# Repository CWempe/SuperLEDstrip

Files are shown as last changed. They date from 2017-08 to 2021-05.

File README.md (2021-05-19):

# SuperLEDstrip

I started this project as a gift for my little cousin.
The goal was to create an LED strip that could be controlled by a kid via touchscreen.
The graphical layout is based on [Googles Material Design Guidelines](https://material.io/guidelines/material-design/introduction.html).

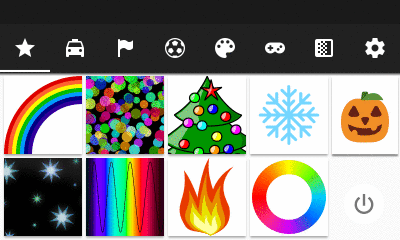
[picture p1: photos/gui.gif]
display animation


SuperLEDstrip v1.0 (http://www.youtube.com/watch?v=CBAr6hmqsu4)

## Requirements

### Hardware

* [**Wemos D1 mini**](https://www.wemos.cc/)  
  An ESP8266 device is nice, because it is litte, cheap and we can add Wifi features later.  
  But any other Arduino compatible device should do.
* [**WS2812B LED strip**](https://de.aliexpress.com/item/2036819167.html)  
  or any other LED strip that is [suported by FastLED](https://github.com/FastLED/FastLED#supported-led-chipsets)
  * It is recommended to use a **capacitor** to smooth out the power supply.  
      I used one with *1000 µF* and *16 V*.
  * [**SK6812**](https://de.aliexpress.com/item/32476317187.html) is also supported since v2.7.0.  
    Define `FASTLED_RGBW` in `custom_values.h`.
    * the white channel is irgnored for now
* **level shifter** from 3.3V to 5V  
  like [Texas Instruments SN74HCT245N](http://www.ti.com/lit/ds/symlink/sn74hct245.pdf)
  * a 20 pin **IC socket** for this chip is a good idea, too
* [**DHT22**](https://www.aliexpress.com/wholesale?SearchText=dht22&opensearch=true)
  to get current temperture and humidity  
  This is not necessary, but it is very cheap. So why not?
* [**Nextion HMI touch screen**](https://nextion.itead.cc/)  
  I used the 3.2" basic model ([NX4024T032](https://www.itead.cc/wiki/NX4024T032))
  You cannot simply use another size without putting much effort into resizing all graphics!
  * a few **connectors** to make it easier to (dis-)connect the display  
    [XHP-4](http://www.jst-mfg.com/product/pdf/eng/eXH.pdf)  
  * a **microSD** card to flash the firmware to the display
* **Power supply** like [this](https://de.aliexpress.com/item/5V-LED-Power-Supply-1A-2A-3A-6A-8A-10A-Switching-Adapter-AC110-240V-AC-to/32810906485.html)
  * a suitable male adapter like [these](https://de.aliexpress.com/item/10-pair-Led-Light-Strip-connector-DC-male-to-DC-female-Plug-Jack-cctv-connect-Adapter/1672619063.html) (not tested)
* **470Ω resistor**
* some more tools, cables and connectors
  * I used [Phoenix Contact MC 1,5/ 3-ST-3,5](http://www.produktinfo.conrad.com/datenblaetter/725000-749999/740631-da-01-en-LEITERPLATTENSTECKER_MC_1_5__3_ST_3_5.pdf) and [MCV 1,5/ 3-G-3,5](http://www.produktinfo.conrad.com/datenblaetter/725000-749999/740686-da-01-en-LEITERPLATTENSTECKER_MCV_1_5__3_G_3_5.pdf) to connect the LED cables, because they are small and are specified to work with the expected current..  
   But they are not good looking.
  * adding a **fuse** is a good idea for security, too

### Software

Using VisualStudio Code and the PlatformIO Extension the necessary libraries are installed automatically vis `platformio.ini`.

Here is the Dependency Graph with the latest successfully tested versions.

```
Dependency Graph
|-- <Homie> 3.0.1
|   |-- <ArduinoJson> 6.11.5
|   |-- <AsyncMqttClient> 0.8.2
|   |   |-- <ESPAsyncTCP> 1.2.0
|   |   |   |-- <ESP8266WiFi> 1.0
|   |-- <Bounce2> 2.55.0
|   |-- <ESP Async WebServer> 1.2.3
|   |   |-- <ESPAsyncTCP> 1.2.0
|   |   |   |-- <ESP8266WiFi> 1.0
|   |   |-- <Hash> 1.0
|   |   |-- <ESP8266WiFi> 1.0
|   |   |-- <ArduinoJson> 6.11.5
|   |-- <Ticker> 1.0
|   |-- <ESP8266WiFi> 1.0
|   |-- <DNSServer> 1.1.1
|   |   |-- <ESP8266WiFi> 1.0
|   |-- <ESP8266HTTPClient> 1.2
|   |   |-- <ESP8266WiFi> 1.0
|   |-- <ESPAsyncTCP> 1.2.0
|   |   |-- <ESP8266WiFi> 1.0
|   |-- <ESP8266mDNS> 1.2
|   |   |-- <ESP8266WiFi> 1.0
|-- <ArduinoJson> 6.11.5
|-- <ESPAsyncTCP> 1.2.0
|   |-- <ESP8266WiFi> 1.0
|-- <DHT sensor library> 1.4.0
|   |-- <Adafruit Unified Sensor> 1.1.4
|-- <DallasTemperature> 3.9.1
|   |-- <OneWire> 2.3.5
|-- <OneWire> 2.3.5
|-- <Nextion> 0.0.0+20201108223110.sha.b8e2a3b
|   |-- <EspSoftwareSerial> 6.8.5
|-- <Embedis> 1.2.0
|-- <Adafruit Unified Sensor> 1.1.4
|-- <elapsedMillis> 1.0.6
|-- <FastLED> 3.3.3
|   |-- <SPI> 1.0
|   |-- <EspSoftwareSerial> 6.8.5
|-- <EEPROM> 1.0
|-- <EspSoftwareSerial> 6.8.5
```

In case you want to edit the content of the display to use other theme colors or add/replace some LED patterns, you also need the following programs.  
Only tested and used with Windows 10.

* [**Nextion Editor**](https://nextion.itead.cc/resource/download/nextion-editor/)  
   This software is needed if you want to change the content of the display
* [**Inkscape**](https://inkscape.org/download)  
   to edit the graphics
* [**inkmake**](https://github.com/wader/inkmake)  
   to automatically create and export the necessary png files from the svg file
  * requires [Ruby](http://rubyinstaller.org/)
* [**msxml**](https://www.microsoft.com/en-us/download/details.aspx?id=21714)  
   to automatically replace colors in the svg file before exporting to png

### Preparation

#### Nextion

Before you can start to compile the project you need to make some changes to the Nextion library.

This is already done in the branch linked in the `platformio.ini`.

Open the following file with a text editor.  
`C:\Users\<username>\Documents\Arduino\libraries\ITEADLIB_Arduino_Nextion\NexConfig.h`

Disable debug by commenting it.

```c
//#define DEBUG_SERIAL_ENABLE  
```

And replace

```c
//#define nexSerial Serial
```

with

```c
#include <SoftwareSerial.h>
extern SoftwareSerial HMISerial;
#define nexSerial HMISerial
```

see:

* <https://github.com/itead/ITEADLIB_Arduino_Nextion#uno-like-mainboards>
* <https://www.reddit.com/r/arduino/comments/4b6jfi/nexconfigh_for_nextion_display_on_arduino_uno/>

You also might want to change some custom values in `custom_values.h`.  
Like `DISPLAY_TITLE`, `DATA_PIN`, `NUM_LEDS`, `LEDS_PER_METER`, `LED_TYPE` or `COLOR_ORDER`.

When using the custom FastLED library you are also able to use RGBW SK6812 strips and DMA mode by defining these features.

## Usage

First you need to combine the hardware components.

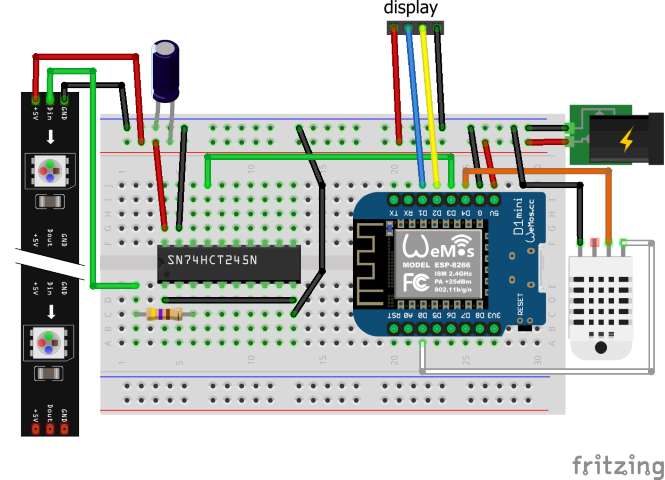
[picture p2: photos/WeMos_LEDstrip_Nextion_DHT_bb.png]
breadboard view


There is also a [pcb view][pcb] when you are done testing. (not tested!)

Next you need to compile and upload the Arduino sketch to your device.
After you installed the libraries you define the parameters of your device before you can hit the upload button.

Be aware to **not connect the LED stripe while the system is only powered by usb** via the Arduino, because this will put to much power through the Arduino. I recomment to disconnect the LED strip and the display while programming the Arduino.

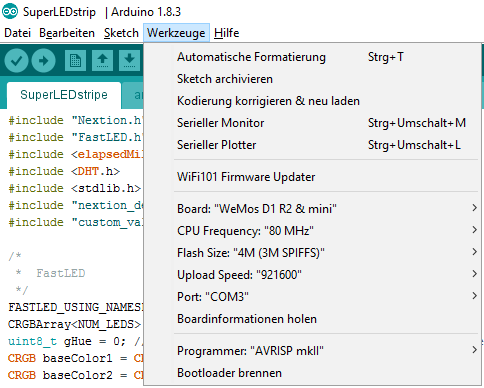
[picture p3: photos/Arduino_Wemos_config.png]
configure serial parameters for Wemos in Arduino


After this you copy the compiled HMI file (will be uploaded to the release page) to an FAT32 formatted microSD card, plug it into the display, and connect power to the display. This will automatically start the flashing of the firmware.

## Customizing

### WLED

Since version `3.1.0` SuperLEDstrip supports controlling a [WLED](https://github.com/Aircoookie/WLED) device.

* Configure `WLED_JSON_URL` in `custom_values.h` befor compiling
* Tested with wled version `0.12.0`.
* Not all scenes look identical to SuperLEDstrip.
* Arcade scenes are not supported.

### Buttons

You can configure the purpose of your buttons in `custom_values.h`.
Like changing tha state of one or multiple output pins or switching between pre-defined scenes.
Just change the values of `button01_do[]`.

### Outputs

You can also define some output pins in `custom_values.h`.
They can be inverted and you can define the initial state at start up.

### Arduino Code

Let's say you want to add an LED pattern you developed as the function `mynewpattern()`.

First you need to add the pattern in `SuperLEDstripe.ino` if you create a new animation.
If your are only ading a new color pattern for an existing animation (like `runningPalette`) you can skip this part.

```c
//     Pattern IDs              0          1      2         3        4    5     6               7              8     9        10  
SimplePatternList gPatterns = { oneColor, stars, confetti, rainbow, bpm, kitt, flashingLights, runningPalette, xmas, Fire2012,  mynewpattern};
```

Add the new secen to the `setScene()` function in `led_functions.h`.

```c
    case 304:   // swedish flag
      setupPaletteSweden();
      break;
```

While you are developing you might want to change the default scene to be your new one.

```c
#define DEFAULT_SCENE      304
```

To start the pattern from a cell (virtual button) from the display, you add the pattern to the according callback function in `nextion_callback_functions.h`.  
Here it is `p01c07PopCallback` (p01 = page 1; c07 = cell 7).

```c
void p01c07PopCallback(void *ptr) { gCurrentPatternNumber = 10; }
```

### Display Graphics

You also need to change the graphics of the display, if you add a new pattern.
First you need to download some pictures from the internet that are not includes in this project.

```c
./Display/exported/get_images.sh
```

Now you can open the `Display\exported\display_matarial_design.svg` with Inkscape and enable the **object manger**.
Next you insert or create your new graphic (we will call it "tile" on top of the cell and group this with the object manager under the tile group of your choice (e.g. "tiles specials").
This is necessary, because the export script will automatically mark the different tile groups as (in-)visible.

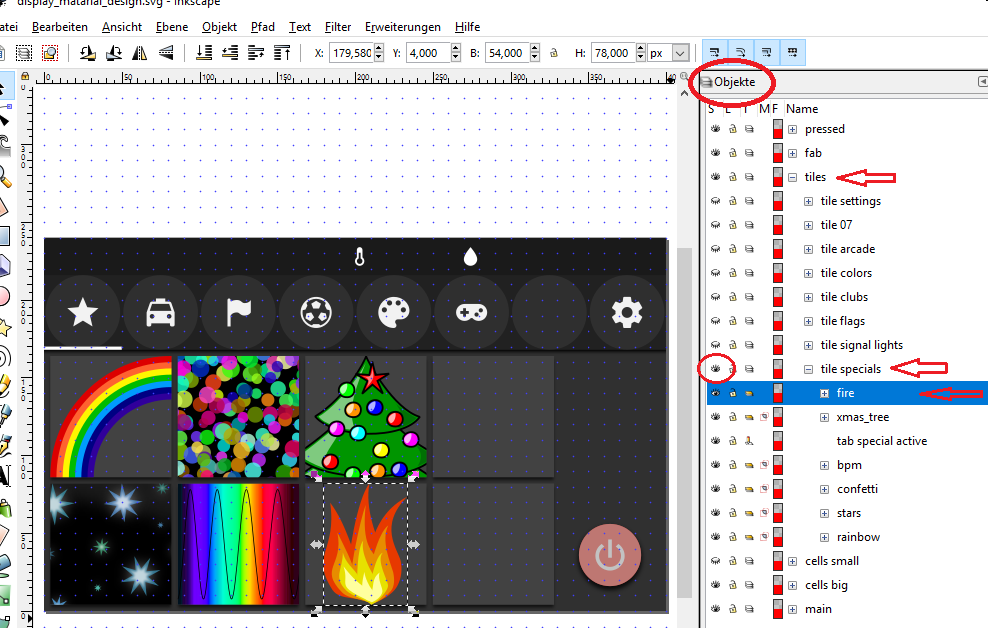
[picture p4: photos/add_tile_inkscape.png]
add tile to graphics


In case you manually export the graphics you might want to change the theme colors and make the individual groups (in-)visible before each export.
For each tile group (settings, flags, ...) you need two exports. One with the `pressed` group disabled and one with it enabled.

The export script `Display\exported\create_colored_svg_custom.bat` will do all this automatically.
To use other theme colors you can change these in line 20.

```c
call:SetColor  dark, white
```

If you run `create_colored_svg.bat` the script will create **all possible color combinations** according to [Googles material design color palette](https://material.io/guidelines/style/color.html#color-color-tool).
It took my computer about **24 hours** to do this!

After the graphics are exported you need to replace the old ones in the Nextion file.  
Open `Display\400x240_black_white_light.HMI` with the Nextion Editor.

Each tabulator of the interface has two pictures within the Nextion file. One with and one without 'pressed' objects.
So for the first tab you need to replace pictures 1 and 2.
Then you select the page (top right corner) and the tile you want the new pattern to be displayed at (here: `p01c07`) and change the attributes (bottem right) `picc` to `1` and `picc2` to `2`.

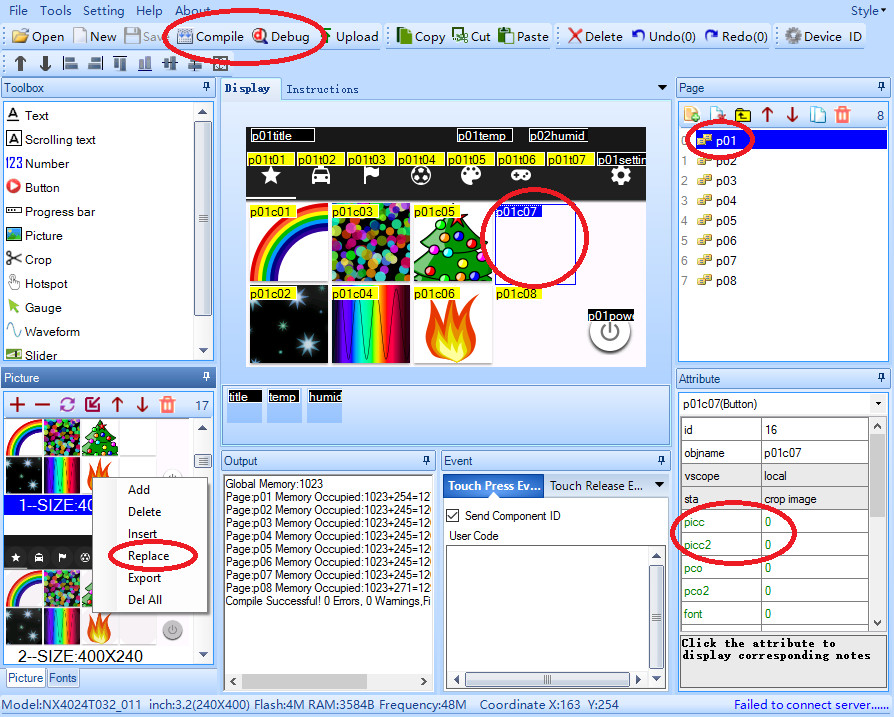
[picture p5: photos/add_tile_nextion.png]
add tile to display


Now you can see the result by clicking `Debug` or hit `Compile` to create a binary file. Put this file (*File | Open build folder*) in the root directory of your microSD card , put it into the display, connect power and wait while the new firmware is flashed.

## OTA-Update

With the integration of homie-esp8266 there comes the ability to flash the firmware via wifi.

* make sure the device is connected to your mqtt broker
* install and configure the [homie-ota server](https://github.com/jpmens/homie-ota)
* download the latest binary firmware release or compile it yourself with the Arduino IDE and select *Sketch | Export compiled Binary*
* Upload the firmware via the web interface of homie-ota or with the `upload_firmware.sh` script
* select firmware and device in the web interface and start the process

## Upload config.json (SPIFFS)

Instead of configuriong your device via the Config-Mode of Homie, you can define your Homie-Configuration in `Data/config.json'.
To upload the file via Seriel (USB) connection use the following command:

`pio run -t uploadfs`

If you use a `d1_mini_pro` board you still need to define `board = d1_mini` in your `platformio.ini`.
Otherwise you get an `std::bad_alloc` error.

## openHAB

Once you got your device connected to your mqtt broker you can configure your smart home (in this case [openHAB](http://www.openhab.org/)) to control SuperLEDstrip.

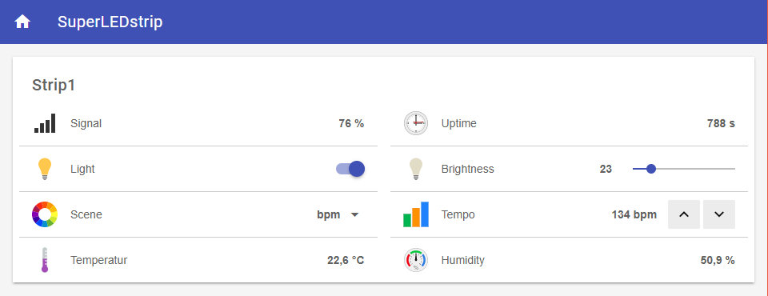
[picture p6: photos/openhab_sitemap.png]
openhab_sitemap


You can find configuration examples in the `openhab` folder.

[display_gif]: photos/gui.gif
[breadboard]: photos/WeMos_LEDstrip_Nextion_DHT_bb.png
[pcb]: photos/WeMos_LEDstrip_Nextion_DHT_pcb.png
[Arduino_Wemos_config]: photos/Arduino_Wemos_config.png
[add_tile_inkscape]: photos/add_tile_inkscape.png
[add_tile_nextion]: photos/add_tile_nextion.png
[openhab_sitemap]: photos/openhab_sitemap.png

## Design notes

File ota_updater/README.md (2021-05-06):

# OTA Update for Homie via MQTT

Example:

```powershell
cd ./ota_updater
pip install -r requirements.txt

python ota_updater.py -l hostname -u user -d password -t "homie/" -i "devicename" ..\.pio\build\d1_mini_pro\firmware.bin

Source: https://github.com/homieiot/homie-esp8266/tree/develop/scripts/ota_updater

Documentation: https://homieiot.github.io/homie-esp8266/docs/3.0.1/others/ota-configuration-updates/
```

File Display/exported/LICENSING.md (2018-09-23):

# halloween pumpkin
source: https://commons.wikimedia.org/wiki/File:Twemoji_1f383.svg

Licens: Creative Commons Attribution 4.0 International license.

https://creativecommons.org/licenses/by/4.0/legalcode

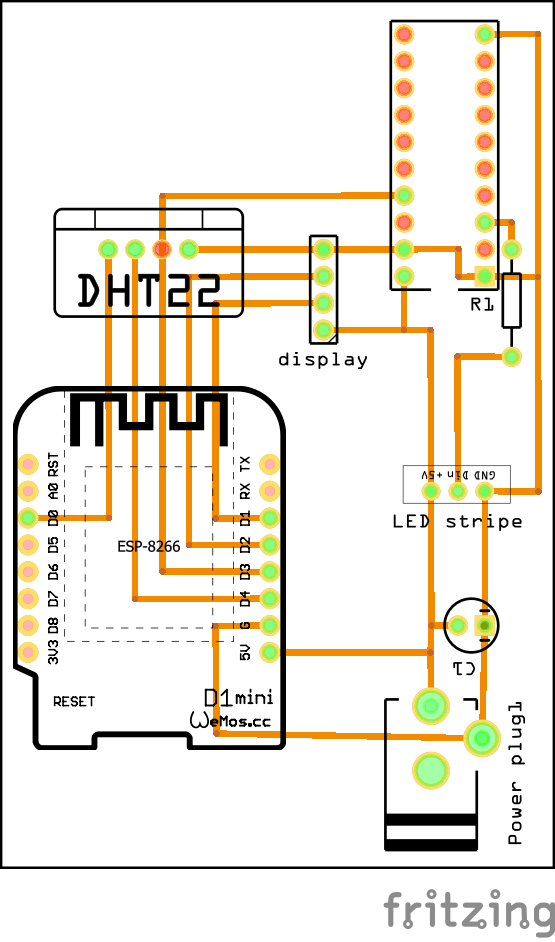
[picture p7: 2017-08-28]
photos/WeMos_LEDstrip_Nextion_DHT_pcb.png

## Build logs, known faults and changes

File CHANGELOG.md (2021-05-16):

# Changelog

## 3.1.0

* Controll a [WLED](https://github.com/Aircoookie/WLED) device (see README)

## 3.0.0

* Switching to Homie 3.0.1 with support of Homie convention v3.0.1
* Control WLED Relay via brightness
* Add `RELAIS_ALWAYS_ON` for WLED pcb

## 2.7.0

* limited support for RGBW (SK6812 LEDs)
* using official FastLED library again

## 2.6.1

* Add pattern "lightsaber"

## 2.6.0

* Make BUTTON01 configurable via `custom_values.h`
* Add OUTPUT pins and make them configurable via `custom_values.h`

## 2.5.4

* Add version number to display

## 2.5.3

* Add USA flag

## 2.5.2

* Make pre defined palletes and pallete scenes selectable via Display

## 2.5.1

* Add support for Button01
  Changes between pre defined scenes

## 2.5.0

* Add color palletes
  * Add pre defines color palletes
  * Add pallete scenes (animation styles) `static pallete`, `running pallete` and `color rotation`
  * Make palletes and pallete scenes selectable via mqtt
  * Make pallete size changeable (via mqtt)
  * Save pallete to eeeprom and restore after reboot

## 2.4.1

* Add option to use DS18B20 instead of DHT22 sensor or neither

## 2.4.0

* Add pattern "custom color"
  * Add support to save and load tweo different custom colrs

## 2.3.0

* Migrate to PlatformIO
* Add option to correct color and color temperature via FastLED
* Move random color pattern to arcade tab
* Add support for RGBW and DMA via custom library ([coryking/FastLED](https://github.com/coryking/FastLED))
* Add support for external graphics in display svg
* Add patterns
  * spanish flag
  * halloween

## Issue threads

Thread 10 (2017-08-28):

add more flags

CWempe, 2017-08-28:
Like

☑ Sweden
☐ England
☐ France
☐ Denmark
☐ Belgium

CWempe, 2017-11-21:
done in new brnach
https://github.com/CWempe/SuperLEDstrip/tree/homie_new_pattern_2017

see: 2b802331c598507a2e48139dd99892c08f5f4497

CWempe, 2017-11-22:
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

Closed 2017-11-21.

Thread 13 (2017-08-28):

add Hue emulation

CWempe, 2017-08-28:
possible projects for inpiration:

* https://github.com/mariusmotea/diyHue
* https://github.com/probonopd/ESP8266HueEmulator

This might add Amazon Alexa support. 😉

needs #3

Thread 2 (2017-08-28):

save last state in persistent memory

CWempe, 2017-08-28:
It would be great if the last choosen led pattern would be saved in EEPROM and be activated after truning the device back on.

This link might help: https://github.com/esp8266/Arduino/tree/master/libraries/EEPROM

CWempe, 2018-09-21:
Fixed in 2712463d415de431c2159e20ac3b4247b710cf4c

Closed 2018-09-21.

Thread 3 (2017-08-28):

add wifi support

CWempe, 2017-08-28:
If this project would support wifi it would be possible to add many nice features that will be mentioned in additional issues.

I guess this would be the best way to integrate wifi.
https://github.com/tzapu/WiFiManager

Additionally it would be nice to show the wifi status on the display and maybe add a wps button in the settings page.

CWempe, 2017-09-01:
I started to integrate homie-esp8266.
see https://github.com/CWempe/SuperLEDstrip/tree/homie

So it supports the following features:

* wifi #3
* mqtt #7
  only device basics, nothing related to LEDs
* OTA-update #5

There may be unknown limitations or disadvantages with this release.
After the first

CWempe, 2017-11-22:
implemented in 78a719ce6630ef17b05810464e2b892e0cef193f

Closed 2017-11-22.

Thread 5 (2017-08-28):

add support for OTA update

CWempe, 2017-08-28:
possibly by adding the [homie framework](https://github.com/marvinroger/homie-esp8266).

Or based on [Sonoff-Tasmota](https://github.com/arendst/Sonoff-Tasmota/)

needs or replaces #3

CWempe, 2017-09-02:
OTA works with the `homie` branch

CWempe, 2017-11-22:
implemented in 60f0dc872d6690895a712106d1c0d880bed533d0

Closed 2017-11-22.

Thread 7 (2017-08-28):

add mqtt support

CWempe, 2017-08-28:
To connect SuperLEDstripe with any kind of smart home it would be great if this project would support [mqtt](http://mqtt.org/).

This requires #3 and might be possible via Homie or Sonoff-Tasmota like mentioned in #5

CWempe, 2017-09-02:
OTA works with the `homie` branch

CWempe, 2017-09-03:
This might be interessting to controll the light via mqtt with openhab.

https://community.openhab.org/t/rgb-led-strip-control-using-arduino-and-mqtt/4366

CWempe, 2017-11-22:
implemented in https://github.com/CWempe/SuperLEDstrip/commit/0126e3e5c56878e3f00e627a10286a83b153a4bb

Closed 2017-11-22.

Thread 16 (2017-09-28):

estimate power consumption

CWempe, 2017-09-28:
Using the following function it shoulkd be possible to estimate the power consumption of the LED strip.
Maybe adding some mW for Arduino and Display.

http://fastled.io/docs/3.1/group___power.html#ga594568be6aba941c635193a6d46f715e

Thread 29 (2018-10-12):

Add support for defining rgb values separately

CWempe, 2018-10-12:
There should be an option to define `rgb` values separately.

# Examples

## mqtt

```
homie/SuperLEDstrip/led/color/set 179,121,63
```

## Display

*mockup*

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

Better use sliders.
https://material.io/design/components/sliders.html#discrete-slider

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

# preperations

* move `colorwheel` tile top `arcade` tab to make room on the `color` tab
*

# features

- [ ] store values in spiff
  * save and load three custom solors
  * not save every change. Let user choose to save current state.
- [ ] restore values and `FastLED.show()` when tile gets opened
- [ ] prepare for future `rgbw` support

CWempe, 2018-11-30:
added in v2.4.0 (e8eb2fa895fcd16d45fbc64f6bade74e0214a76d)

Closed 2018-11-30.

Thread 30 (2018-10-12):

Fix warnings found by PlatformIO

CWempe, 2018-10-12:
When comiling with PlatformIO there are several warnings like the following.

```
C:\Users\cwempe\.platformio\packages\framework-arduinoespressif8266\libraries\SoftwareSerial\SoftwareSerial.cpp: In member function 'void SoftwareSerial::rxRead()':
C:\Users\cwempe\.platformio\packages\framework-arduinoespressif8266\libraries\SoftwareSerial\SoftwareSerial.cpp:219:16: warning: comparison between signed and unsigned integer expressions [-Wsign-compare]
if (next != m_outPos) {
^

.piolibdeps\Nextion_ID37\NexPage.cpp: In member function 'bool NexPage::show()':
.piolibdeps\Nextion_ID37\NexPage.cpp:25:13: warning: unused variable 'buffer' [-Wunused-variable]
uint8_t buffer[4] = {0};
^
```

CWempe, 2018-11-30:
Fixed almost all in a2f44fe2a5357fa0bc315a70bcc254fc4be914c6

Closed 2018-11-30.

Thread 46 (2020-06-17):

Set versionss of libraries in platformio.ini

CWempe, 2020-06-17:
Some newer libraries create problems.
`platformio.ini` should have the working versions predefined.

CWempe, 2020-06-17:
This might help:

```ini

     ; Homie@2.0.0
     Homie
     ; ESPAsyncTCP@1.2.0
     ESPAsyncTCP
     ; DHT sensor library@1.3.4
     DHT sensor library
     DallasTemperature
     ; OneWire@2.3.4
     OneWire
     Nextion
     ; FastLED_RGBW=git@github.com:coryking/FastLED.git
     FastLED_RGBW=git@github.com:cwempe/FastLED.git#support_new_esp8266_lib
     Embedis
     Adafruit Unified Sensor
     ; elapsedMillis@1.0.4
     elapsedMillis
```

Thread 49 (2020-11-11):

virtual Power button not working in halloween scene

CWempe, 2020-11-11:
looks liek the flickering sets the brightness back up

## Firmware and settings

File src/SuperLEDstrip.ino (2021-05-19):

//include global and custom values
#include "global_values.h"
#include "custom_values.h"

// include libraries
#include <Nextion.h>
#include <elapsedMillis.h>
#include <stdlib.h>
#include <Homie.h>
#include <EEPROM.h>
#include <Embedis.h>
#include <spi_flash.h>
#include <SoftwareSerial.h>
#include <FastLED.h>
#include <FastLED_RGBW.h>

#ifdef SENSOR_DHT
  #include <DHT.h>
#endif
#ifdef SENSOR_DS18B20
  #include <DallasTemperature.h>
  #include <OneWire.h>
#endif


/*
 * Function prototypes
 */
void setTextAllSensors(void);
void Fire2012(void);
void arc_pulse(void);
void setupHalloween(void);
void staticPalette();
void showPalette (uint8_t colorIndex);
void halloween(void);
void setScene(uint16_t scene);
void setPalette(uint8_t palette);
void setBrightness(uint8_t newBrightness);
void setTempo(uint8_t tempo);
#ifdef FASTLED_RGBW
  void fill_part( struct CRGBW * leds, int numFromFill, int numToFill, CRGB color);
#else
  void fill_part( struct CRGB * leds, int numFromFill, int numToFill, CRGB color);
#endif

void updateTab(void);
void setTextAll(void);
void setTextAllSensors(void);
void setTextHumid(void);
void setTextTemp(void);
void setTextTitle(void);
void setTextRotationSpeed(void);
void updateRotationSpeed(void);
void changeRotationSpeed(bool increaseSpeed);
void setRotationSpeed(uint8_t speed);
void setPaletteSize(uint8_t paletteSize);
void getRed(void);
void getGreen(void);
void getBlue(void);
void updateCustomColorRed(uint8_t red, bool updateRGB);
void updateCustomColorGreen(uint8_t green, bool updateRGB);
void updateCustomColorBlue(uint8_t blue, bool updateRGB);
void updateButton01switch(String value, bool write);
void updateButton01event_on_press(String value, bool write);
void updateButton01action(String value, bool write);
void updateOutput01on(String value, bool write);
void updateOutput01invert(String value, bool write);
void updateOutput02on(String value, bool write);
void updateOutput02invert(String value, bool write);
void updateOutput03on(String value, bool write);
void updateOutput03invert(String value, bool write);
void updateOutput04on(String value, bool write);
void updateOutput04invert(String value, bool write);
void readEepromScene(void);
void calculateNextIndex(uint8_t *index, bool *momentum);
#ifdef WLED_ENABLE
  void wled_power(void);
  void wled_send_json(String json);
#endif


Embedis embedis(Serial);


/*
 * #############################
 * ### WLED ontrol Functions ###
 * #############################
 */

#ifdef WLED_ENABLE
  String wled_pal = "0";
  String wled_fx = "0";
  String wled_ix = "128";
  String wled_sx = "128";
  String wled_bri = "128";
  String wled_pal_custom = "";

  #include "wled_control.h"
#endif

/*
 *  FastLED
 */
//  Definitions for FastLED RGBW Hack
#ifdef FASTLED_RGBW
  // FastLED with RGBW
  CRGBW leds[NUM_LEDS];
  // CRGBArray<NUM_LEDS> leds;
  CRGB *ledsRGB = (CRGB *) &leds[0];
#else
  // CRGB leds[NUM_LEDS];
  CRGBArray<NUM_LEDS> leds;
#endif
FASTLED_USING_NAMESPACE 
uint8_t gHue  = 0; // rotating "base color" used by many of the patterns
uint8_t gHue2 = 0; // rotating "color" incremented by some pattern with specific speed
uint8_t rotationSpeed = DEFAULT_ROTATION_SPEED; // default speed for color rotation
int rotationSpeedMs; // rotationSpeed converted to delay between color changing in ms
uint8_t paletteSize = DEFAULT_PALETTESIZE;
uint8_t incIndex = 255 / NUM_LEDS * paletteSize;
static CEveryNMilliseconds ColorRotation(100);
CRGB baseColor1 = CRGB::Blue;
CRGB baseColor2 = CRGB::Blue;
CRGB customColor = CRGB(255,255,255);
// Array of random default colors
CRGB randomColorArray[] = {CRGB::White, CRGB( 255, 147, 41), CRGB::Red, CRGB::Green, CRGB::Blue, CRGB::Magenta, CRGB::Cyan, CRGB::Yellow};
uint8_t randomColorsCountdown = 2;    // will be set to 0 (disable countdown) via first use of setupRandomColor
CRGBPalette16 currentPalette;
CRGBPalette16 targetPalette;
TBlendType    currentBlending;
uint8_t currentBrightness = DEFAULT_BRIGHTNESS;
uint8_t gCurrentPatternNumber; // Index number of which pattern is current
uint8_t gLastPatternNumber = 255;
elapsedMillis timeElapsed1;
elapsedMillis timeElapsed2;
uint8_t BeatsPerMinute = DEFAULT_TEMPO;
CRGB halloweenColorArray[] = {CRGB::White, CRGB::LimeGreen, CRGB::BlueViolet}; //
uint16_t halloweenFlickerTimer = 1000;  // initial flicker timer value
bool     halloweenFlickerState = false; // helper to save current state of flickering; true = light of
uint16_t halloweenFlashTimer = 1000;    // initial flash timer value
bool     halloweenFlashState = false;   // helper to save current state of flashing; true = flashing on
bool     paletteRotationable = true;    // helper to define if a palette can be attatched to itselfe nicely
bool     startPaletteInverted = false;
bool     paletteMomentumStart = true;   // Defines the momentum of the palette (forward or reverse) at the first pixel of the stripe.
                                        // The color index of the palette might descend from 255 to 0 if it cannot attached back to back.
bool     paletteMomentumPixel = true;   // Same as paletteMomentumPixel but for each pixel of the strip.
bool     invert = false;
uint8_t  maxChanges = 10;               // How fast should palettes change (1-48)
bool     fadePalette = true;
bool     autoChangePalette = false;     // automatically change palette
uint16_t autoChangePaletteMS = 5000;       // automatically change palette every X seconds

//  lightsaber
bool    lightsaber_growing        = false;
uint8_t lightsaber_lenght_current = 0;
CRGB    lightsaber_color_current  = CRGB::Green;
CRGB    lightsaber_color_target   = CRGB::Green;
// millisenconds to turn on/off the lightsaber, smaller value = faster
#define LIGHTSABER_SPEED            300

bool updateDisplayRed   = false;
bool updateDisplayGreen = false;
bool updateDisplayBlue  = false;


/*
 * Nextion display
 */
SoftwareSerial HMISerial(NEXTION_TX, NEXTION_RX);

/*
 * DHT and DS18B20
 */
#if defined(SENSOR_DHT) || defined(SENSOR_DS18B20)
  float fTemp         = 0;
  char  sTemp[10]     = "";
  HomieNode temperatureNode("temperature", "temperature", "temperature");
#endif
#ifdef SENSOR_DHT
  float fHumid        = 0;
  char  sHumid[10]    = "";
  HomieNode humidityNode("humidity", "humidity");
  #include "dht_functions.h"
#endif
#ifdef SENSOR_DS18B20
  OneWire oneWire(TEMP_DATA_PIN);
  DallasTemperature sensors(&oneWire);
  #include "temp_functions.h"
#endif


HomieNode lightNode("light", "light switch", "switch");
#include "eeprom_functions.h"

#include "outputs.h"
#include "buttons.h"

/*
 * #########################
 * ### FastLED Functions ###
 * #########################
 */

#include "lightsaber.h"
#include "led_patterns.h"
#include "led_palette_functions.h"
#include "led_palettes.h"
#include "pattern_halloween.h"

typedef void (*SimplePatternList[])();
SimplePatternList gPatterns = { oneColor,          //  0
                                stars,             //  1
                                confetti,          //  2
                                rainbow,           //  3
                                bpm,               //  4
                                kitt,              //  5
                                flashingLights,    //  6
                                runningPalette,    //  7
                                xmas,              //  8
                                Fire2012,          //  9
                                arc_pulse,         // 10
                                ice,               // 11
                                randomColor,       // 12
                                colorRotation,     // 13
                                halloween,         // 14
                                staticPalette,     // 15
                                lightsaber         // 16
                               };


#include "led_functions.h"
#include "led_custom_color.h"


/*
   #########################
   ### Nextion Functions ###
   #########################
*/

#include "nextion_declaration.h"
#include "nextion_registration.h"
#include "nextion_callback_functions.h"
#include "nextion_initialization.h"
#include "nextion_functions.h"


/*
   #######################
   ### Homie Functions ###
   #######################
 */

void setupHandler() {
  #if defined(SENSOR_DHT) || defined(SENSOR_DS18B20)
    if (Homie.isConnected()) temperatureNode.setProperty("unit").send("°C");
  #endif
  #ifdef SENSOR_DHT
    if (Homie.isConnected()) humidityNode.setProperty("unit").send("%");
  #endif
  
}

bool lightBrightnessHandler(const HomieRange& range, const String& value) {
  Homie.getLogger() << "Brightness is " << value << endl;
  setBrightness(value.toInt());
  return true;
}

bool lightSceneHandler(const HomieRange& range, const String& value) {
  setScene(value.toInt());
  return true;
}

bool lightPaletteHandler(const HomieRange& range, const String& value) {
  if ( value.toInt() == 0 ) {
    autoChangePalette = true;
  } else {
    autoChangePalette = false;
    setPalette(value.toInt());
  }
  return true;
}

bool lightTempoHandler(const HomieRange& range, const String& value) {
  setTempo(value.toInt());
  return true;
}

bool lightRotationSpeedHandler(const HomieRange& range, const String& value) {
  setRotationSpeed(value.toInt());
  return true;
}

bool lightPaletteSizeHandler(const HomieRange& range, const String& value) {
  setPaletteSize(value.toInt());
  return true;
}



bool lightOnHandler(const HomieRange& range, const String& value) {
  if (value != "true" && value != "false") return false;

  bool on = (value == "true");
  FastLED.setBrightness(on ? currentBrightness : 0);
  #ifdef WLEDSHIELD
    // Turn off Relais if brightness is set to 0; else torn on
    updateOutput01on((on ? "true" : "false"));
  #endif
  if (Homie.isConnected()) lightNode.setProperty("on").send(value);
  lightON = (value == "true");
  Homie.getLogger() << "Light is " << (on ? "on" : "off") << endl;

  return true;
}

bool globalInputHandler(const HomieNode& node, const HomieRange& range, const String& property, const String& value) {
  Homie.getLogger() << "Received on node " << node.getId() << ": " << property << " = " << value << endl;
  
  return false;
}

void loopHandler() {
  
}


/*
   ######################
   ### Main Functions ###
   ######################
*/
void setup(void)
{
  Serial.begin(115200);
  setupEeprom();
  
  if ( DEBUGLEVEL >= 1 ) {
    Homie.getLogger() << "" << endl;
    Homie.getLogger() << "[DEBUG1] starting..." << endl;
  }

  #ifdef SENSOR_DHT
    setupDHT();
  #endif
  #ifdef SENSOR_DS18B20
    setupTemp();
  #endif

  Homie_setFirmware(HOMIE_FW_NAME, HOMIE_FW_VERSION); // The underscore is not a typo! See Magic bytes
  Homie.disableResetTrigger();                 // disable ResetTrigger, because it creates some problemes for me
  //Homie.setStandalone();                     // uncomment if you do not want to use wifi
  Homie.setSetupFunction(setupHandler).setLoopFunction(loopHandler);
  #if defined(SENSOR_DHT) || defined(SENSOR_DS18B20)
    temperatureNode.advertise("unit");
    temperatureNode.advertise("degrees");
  #endif
  #ifdef SENSOR_DHT
    humidityNode.advertise("percentage");
  #endif
  lightNode.advertise("on").settable(lightOnHandler);
  lightNode.advertise("customColor").settable(lightCustomColorHandler);
  lightNode.advertise("brightness").settable(lightBrightnessHandler);
  lightNode.advertise("scene").settable(lightSceneHandler);
  lightNode.advertise("palette").settable(lightPaletteHandler);
  lightNode.advertise("tempo").settable(lightTempoHandler);
  lightNode.advertise("rotationSpeed").settable(lightRotationSpeedHandler);
  lightNode.advertise("paletteSize").settable(lightPaletteSizeHandler);
  Homie.setGlobalInputHandler(globalInputHandler);
  if ( HOMIE_STANDALONE == true ) {
    Homie.setHomieBootMode(HomieBootMode::STANDALONE);
  }
  #ifdef BUTTON01_PIN
    HomieSetupButton01();
  #endif
  #ifdef OUTPUT01_PIN
    HomieSetupOutput01();
  #endif
  #ifdef OUTPUT02_PIN
    HomieSetupOutput02();
  #endif
  #ifdef OUTPUT03_PIN
    HomieSetupOutput03();
  #endif
  #ifdef OUTPUT04_PIN
    HomieSetupOutput04();
  #endif

  Homie.setup();  
  NextionSetup();
  setTextTitle();
  delay(1000);
  setupFastLED();
}

void loop(void)
{
  nexLoop(nex_listen_list);

  EVERY_N_MILLISECONDS( 20 ) {
    gHue++;  // slowly cycle the "base color" through the rainbow
  }
  // Call FastLED commands every 1/120th ms
  EVERY_N_MILLISECONDS(1000 / DEFAULT_FPS)
  {
    loopFastLED();
  }

  // Test WLED_command
  // EVERY_N_MILLISECONDS(1000 * 10)
  // {
  //   wled_power(true);
  // }

  #ifdef SENSOR_DHT
    loopDHT();
  #endif
  #ifdef SENSOR_DS18B20
    EVERY_N_SECONDS(SENSOR_READ_INTERVAL) {
      loopTemp();
    }
  #endif

  #ifdef BUTTON01_PIN
    loopButton01();
  #endif

  Homie.loop();

  updateDisplayColors();
  
}

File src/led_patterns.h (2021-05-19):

void oneColor()
{
  // nothing changes over time in this this color pattern
  fill_solid(leds, NUM_LEDS, baseColor1);
}

void setupOneColor(CRGB color)
{
  // set firt LED to selected color when arcade pattern is active
  if ( gCurrentPatternNumber >= 10 && gCurrentPatternNumber <= 10 ) {
    leds[0] += color;
  } else if ( gCurrentPatternNumber == 16 ) {
    // set new color for lightsaber
    lightsaber_color_target = color;
    if ( lightsaber_color_current == lightsaber_color_target ) {
      lightsaber_toggle();
    }
  }
  else {
    // else set the whole stripe in one color
    baseColor1 = color;
    gCurrentPatternNumber = 0;
  
    // WLED
    #ifdef WLED_ENABLE
      char baseColor1red [4];
      char baseColor1green [4];
      char baseColor1blue [4];
      String sBaseColor1red;
      String sBaseColor1green;
      String sBaseColor1blue;

      // Convert integer to char
      snprintf(baseColor1red, 4, "%u", color.red);
      snprintf(baseColor1green, 4, "%u", color.green);
      snprintf(baseColor1blue, 4, "%u", color.blue);
      
      // Convert char to String
      sBaseColor1red += baseColor1red;
      sBaseColor1green += baseColor1green;
      sBaseColor1blue += baseColor1blue;

      wled_send_json("{\"on\":true,\"seg\":[{\"col\":[[" + sBaseColor1red + "," + sBaseColor1green + "," + sBaseColor1blue + "],[0,0,0],[0,0,0]],\"fx\":83,\"pal\":0}]}}");

      if ( DEBUGLEVEL >= 1 ) {
        Homie.getLogger() << "[DEBUG1] baseColor1 red:   " << sBaseColor1red << endl;
        Homie.getLogger() << "[DEBUG1] baseColor1 green: " << sBaseColor1green << endl;
        Homie.getLogger() << "[DEBUG1] baseColor1 blue:  " << sBaseColor1blue << endl;
      }
    #endif
  }
}

void randomColor()
{
  // show random color three times a secondd and stay after 20 iterations
  EVERY_N_MILLIS_I(RandomColor, 1000/3)
  {
    // keep showing colors when countdown is still running or disabled
    if ( randomColorsCountdown > 1 || randomColorsCountdown == 0 ) {
      // generate random color until it is different to the last color
      do {
        baseColor2 = baseColor1;
        baseColor1 = randomColorArray[random(8)];
      } while ( baseColor1 == baseColor2 ) ;
      fill_solid(leds, NUM_LEDS, baseColor1);
      if ( randomColorsCountdown > 1 ) {
        // if countdown is running then descrease countdown
        randomColorsCountdown--;
      }
    }
  }
}

void setupRandomColor()
{
Homie.getLogger() << "setupRandomColor started... " << endl;
  if ( randomColorsCountdown == 0 ) {
    // if countdown is disabled, start countdown
    // 6 = schow five more colors
    randomColorsCountdown = 6;
  } else {
    // else disable countdown
    randomColorsCountdown = 0;
  }
  gCurrentPatternNumber = 12;
}

#ifdef FASTLED_RGBW
  void fill_part( struct CRGBW * leds, int numFromFill, int numToFill, CRGB color)
  {
    if ( numFromFill <= numToFill ) {
      for( int i = numFromFill; i < numToFill; i++) {
        leds[i] = color;
      }
    }
  }
#else
  void fill_part( struct CRGB * leds, int numFromFill, int numToFill, CRGB color)
  {
    if ( numFromFill <= numToFill ) {
      for( int i = numFromFill; i < numToFill; i++) {
        leds[i] = color;
      }
    }
  }
#endif

void FillLEDsFromPaletteColors( uint8_t colorIndex)
{
    uint8_t brightness = 255;
    
    for( int i = 0; i < NUM_LEDS; i++) {
        leds[i] = ColorFromPalette( currentPalette, colorIndex, brightness, currentBlending);
        colorIndex += 3;
    }
}

void runningPalette()
{
  static uint8_t startIndex = 0;
  
  // generate led array based on the current startIndex
  showPalette(startIndex);

  EVERY_N_MILLIS_I(runningPalette, rotationSpeedMs / 10) {
    // calculate next index of palette for the first pixel
    calculateNextIndex( &startIndex, &paletteMomentumStart );
    
    // Update Timer
    runningPalette.setPeriod(rotationSpeedMs / 10);
  }
}

void colorRotation()
{
  static uint8_t startIndex = 0;
  // static CRGB color;

  EVERY_N_MILLIS_I(runningPalette, rotationSpeedMs / 10) {
    calculateNextIndex( &startIndex, &paletteMomentumStart );
    // Update Timer
    runningPalette.setPeriod(rotationSpeedMs / 10);
  }
  fill_solid(leds, NUM_LEDS, ColorFromPalette( currentPalette, startIndex, 255));
}


// This function sets up a palette of Bayern Munich.
void setupPaletteBayern() {
  gCurrentPatternNumber = 7;
  currentBlending = NOBLEND;
  setPalette(150);
}

// This function sets up a palette of white and brightblue stripes.
void setupPalette1860() {
  gCurrentPatternNumber = 7;
  currentBlending = NOBLEND;
  setPalette(151);
}

// This function sets up a palette of green stripes.
void setupPaletteBVB() {
  gCurrentPatternNumber = 7;
  currentBlending = NOBLEND;
  setPalette(152);
}

// This function sets up a palette of green stripes.
void setupPaletteWerder() {
  gCurrentPatternNumber = 7;
  currentBlending = NOBLEND;
  setPalette(153);
}

// This function sets up a palette of green stripes.
void setupPaletteESV() {
  gCurrentPatternNumber = 7;
  currentBlending = NOBLEND;
  setPalette(154);
}

// This function sets up a palette of green stripes.
void setupPaletteHSV() {
  gCurrentPatternNumber = 7;
  currentBlending = NOBLEND;
  setPalette(155);
}

// This function sets up a palette of the german flag.
// also works for Belgium
void setupPaletteGermany() {
  gCurrentPatternNumber = 7;
  currentBlending = NOBLEND;
  setPalette(180);
}

// This function sets up a palette of the italian flag.
void setupPaletteItaly() {  
  gCurrentPatternNumber = 7;
  currentBlending = NOBLEND;
  setPalette(181);
}

// This function sets up a palette of the brazilian flag.
void setupPaletteBrazil() {
  gCurrentPatternNumber = 7;
  currentBlending = NOBLEND;
  setPalette(182);
}

// This function sets up a palette of the swedish flag.
void setupPaletteSweden() {
  gCurrentPatternNumber = 7;
  currentBlending = NOBLEND;
  setPalette(183);
}

// This function sets up a palette of the english flag.
// also works for Denmark
void setupPaletteEngland() {
  gCurrentPatternNumber = 7;
  currentBlending = NOBLEND;
  setPalette(184);
}

// This function sets up a palette of the french flag.
void setupPaletteFrance() {
  gCurrentPatternNumber = 7;
  currentBlending = NOBLEND;
  setPalette(185);

}

// This function sets up a palette of the spanish flag.
void setupPaletteSpain()
{
  gCurrentPatternNumber = 7;
  currentBlending = NOBLEND;
  setPalette(186);
}

// This function sets up a palette of the american flag.
void setupPaletteUSA()
{
  gCurrentPatternNumber = 7;
  currentBlending = NOBLEND;
  setPalette(187);
}

void stars()
{
  fadeToBlackBy( leds, NUM_LEDS, 1);
  if ( random8() < 8) {
    leds[ random16(NUM_LEDS) ] += CRGB::White;
  }
}

void confetti()
{
  // random colored speckles that blink in and fade smoothly
  fadeToBlackBy( leds, NUM_LEDS, 10);
  
  EVERY_N_MILLISECONDS(1000/NUM_LEDS/2)
  {
    int pos = random16(NUM_LEDS);
    leds[pos] += CHSV( random8(255), 200, 255);
  }
}
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

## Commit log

2016-12-10 added Adafruit Unified Sensor library
2016-12-11 added compatible board info for esp2866
2016-12-11 changes LED DATA_PIN to D3 for compatibility with esp8266-2.3.0
2016-12-11 added fritzing files
    [WeMos_LEDstrip_Nextion_DHT_LED.fzz, WeMos_LEDstrip_Nextion_DHT_LED_printed-circuit-board.fzz]
2016-12-13 added triggering to new xmas button
2017-05-28 use color buttons to send pulses in arcade mode
2017-08-28 update Fritzing
    [WeMos_LEDstrip_Nextion_DHT_LED.fzz]
2017-08-28 raname Fritzing files
    [WeMos_LEDstrip_Nextion_DHT.fzz, WeMos_LEDstrip_Nextion_DHT_printed-circuit-board.fzz]
2017-08-28 recreate pcb view in WeMos_LEDstrip_Nextion_DHT.fzz
    [WeMos_LEDstrip_Nextion_DHT.fzz, WeMos_LEDstrip_Nextion_DHT_printed-circuit-board.fzz]
2017-08-28 link to pcb view in README
2017-08-28 fix typo in project name
    [SuperLEDstrip.ino]
2017-09-01 auto correct coding of files
    [arcade.ino, led_patterns.h, pattern_Fire2012.ino]
2017-09-01 add node temperature
2017-09-02 link light node to power button
2017-09-02 make light switch work offline and change lightOFF to lightON
2017-09-02 outsource led_functions and nextion_functions
2017-11-21 Fix comments for flag pattern
    [led_functions.h, led_patterns.h]
2017-11-21 Add swedish, english, french, danish and belgium flags to arduino
2017-11-22 Add ice scene to arduino
2018-05-31 Add led function RandomColor
2018-05-31 Add 9th button to page 5 of display and nextion functions
2018-06-01 Replace dice with color wheel in svg and HMI
2018-06-01 Stop randomColor via countdown every second button push
2018-06-01 Prevent random color to be the same back to back
    [led_patterns.h]
2018-06-01 Reset randomColorsCountdown if another scene is selected
    [led_functions.h]
2018-06-01 Add led function setupPaletteESV
2018-06-01 Fix starting wrong function fpr scene 405
    [led_functions.h]
2018-06-02 Add led pattern colorRotation
2018-06-02 Add led pattern colorRotation to svg and HMI
2018-09-23 Add color temperature and correction
    [led_functions.h]
2018-09-23 Use currentBrightness for halloween
2018-10-12 Define RGBW and DMA in custom_values.h
2018-10-17 Send RGB from display sliders to led strip
2018-10-17 Fix settings button on page 9 in HMI
2018-11-25 Add scene 509 to led_functions
2018-11-30 Prepare temp sensor to be user defined
2018-11-30 Fix some minor warning reported by PIO
    [led_patterns.h]
2018-12-01 Add option to use DS18B20 sensor
2018-12-09 Add currentBlending to palette definitions
2019-02-27 Support Button01
2019-02-27 Add scenes for Button01
2019-02-27 Add Button01 definition to custom_values
2019-08-11 Add nextion buttons p07c09-16 to code
2019-08-24 Add american flag scene (LED)
2019-08-24 Fix version number gets concated mulitple times
    [SuperLEDstrip.ino]
2019-12-01 Change board to d1_mini_pro
2019-12-05 Make BUTTON01 configurable via custom_values.h
2019-12-05 Publish BUTTON01 settings via mqtt
2019-12-05 Make BUTTON01 settings configurable via mqtt
2019-12-06 (Re)store button01 settings in Eeprom
2019-12-07 Reorganize button01 functions
2019-12-07 Add setting to invert OUTPUT01
    [outputs.h]
2019-12-07 Fix output01_invert not correctly written to Eeprom
    [outputs.h]
2019-12-07 Correct publich to publish
    [outputs.h]
2019-12-08 Outsource update and publish for Button01
2019-12-08 Make outputs controllable via BUTTON01
2019-12-08 Print Button state only in DEBUG mode
2020-03-07 Add documentation of buttons and outputs top README
2020-10-25 Use fixed FastLED branch for RGBW without DMA
2020-11-07 Optimize custom_values.h.example for different PCBs
2020-11-09 Add RGBW versions of used led functions
2020-11-11 Fix last LED not written via fill_part()
    [led_functions.h, led_patterns.h]
2020-11-11 Add RELAIS_ALWAYS_ON for WLED pcb
2021-05-11 Fix bug in kitt() function
    [led_patterns.h]
2021-05-15 Fix rainbow scene for wled
    [led_functions.h]
2021-05-15 Fix color rotation rainbow scene for wled
    [led_functions.h]
2021-05-16 Add missing initialization of wled_bri
    [SuperLEDstrip.ino]
